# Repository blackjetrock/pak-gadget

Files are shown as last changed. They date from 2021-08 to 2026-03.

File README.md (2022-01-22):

# pak-gadget
Psion Organiser II datapak replacement using RP2040

Code for a replacement Psion datapak that uses the RP2040 to create a datapak image that is interfaced using one of the datapak slots in the Organiser.
The gadget has an SD slot that can hold .opk files which are presented to the organiser as a datapak. There's a small OLED display and buttons so the image can be selected. The pak gadget can also present a rampak and data can be stored on the ram pak. That can then be saved to SD card using the menu system.
Power is USB as the datapak interface does not have a permanent power supply.

There are two versions:

Breakout pak-gadget
===================

A 'breakout' pak-gadget which is a T shaped PCB that plugs in to the datapak slot and has the display and buttons facing forwards. This is quite large.

Pak Sized pak-gadget
====================

This is a pak-gadget that fits in the form factor of a datapak in the slot in the organiser. It has a smaller OLED display and buttons that both face towards the back of the organiser. Power is still USB. When disconnected from power the organiser cover should fit in the closed position. The gadget can be wired in to the internal power supply of the organiser.On older PCB designs this requires an external transistor and a wire to the gadget. The later designs have that on the gadget PCB and require two wires.

Operation
=========

The pak gadget plugs in to either datapack slot on a Psion Organiser 2. It can be powered by the USB socket on the PCB, or it can be wired in to the 
internal supply of the organiser. A transistor is needed to switch the battery voltage on to the gadget when the LCD controller is turned on. When wired in 
the USB connection MUST NOT be used. A later revision of the PCB (untested as yet) has the extra transistor needed for internal power on the PCB.

The gadget runs in a tight loop when emulating a datapack in order to operate at the speeds needed to interact with the Psion, which means it cannot handle a 
menu while emulating.

There are four buttons on the gadget. The left most button breaks the gadget out of its tight loop and starts a menu. UP and DOWN are the rightmost two 
buttons. The button second from left is an OK button.

The code reads a file called config.txt from the SD card when it starts up. At the moment this just sets the .OPK image that will initially be used.
pack header bytes are passed through from the OPk file to the organiser unchanged, apart from the size byte. The pak gadget can only support pack images up to 
and including 128K so the size byte is altered to be no larger than 128K.

Menu options
============

List
----
This lists the .OPK files on the SD card. Selecting a file loads it into the gadget RAM buffer ready to emulate it when the menu is exited.

Write
-----
This writes the current RAM data to a file on the SD card. This enables a pak gadget that has been used as a RAM pack to save the data on SD card so that 
it can be loaded back in later. When power is removed the RAM b uffer is lost so this is the only way to have non volatile storage with the pak gadget.

The files are written with the name:
paknnnnn.opk

where nnnnn is an increasing number for each file saved. The pak gadget checks for the last nnnnn used by a file on the SD card and picks the next 
highest number for each file write.

Blank
-----
This clears the RAM buffer and sets the pak gadget up as a blank pack which can then be sized and used as a RAM pack.

Exit
----
This exits the menu and enters the emulation loop so that the pak gadget will look like a datapack again. While in the menu system the gadget does not emulate a pack.

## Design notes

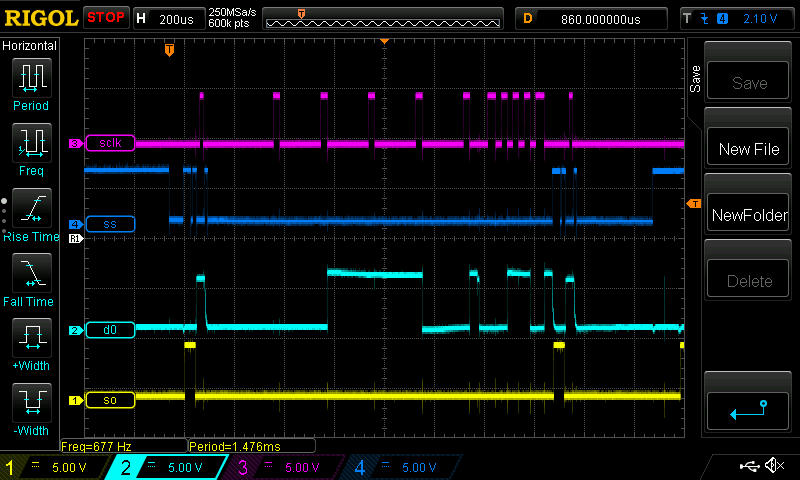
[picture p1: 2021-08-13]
eclipse/pak-gadget/scope_traces/rra2.jpg

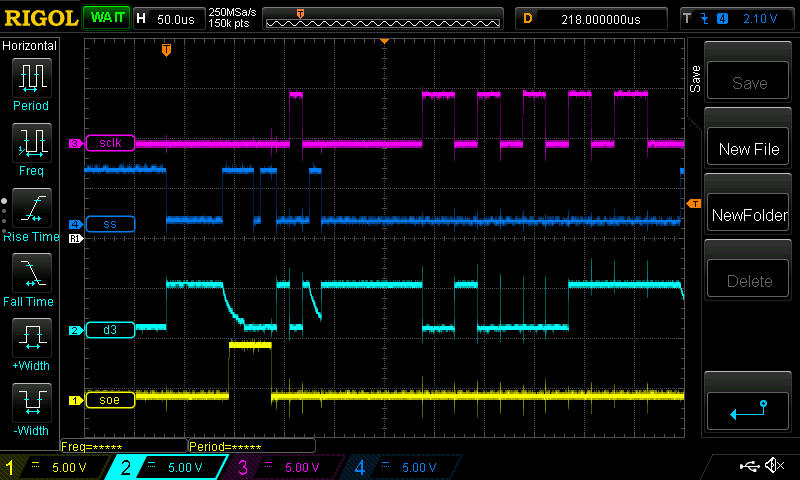
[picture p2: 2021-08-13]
eclipse/pak-gadget/scope_traces/NewFile3.jpg

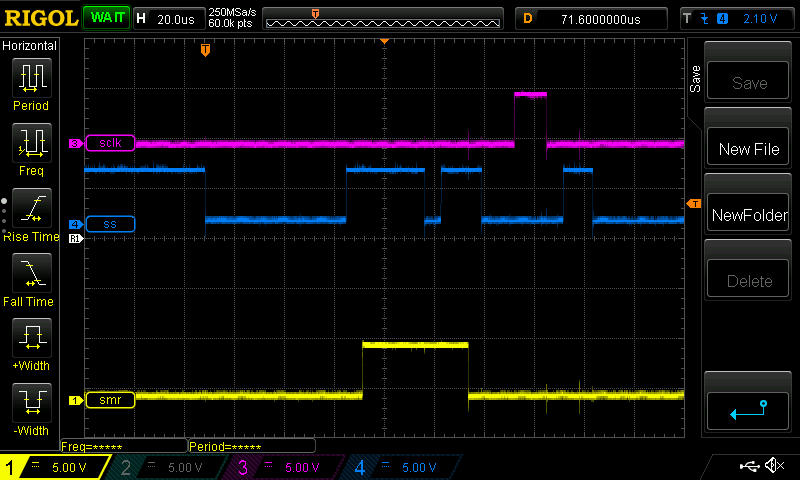
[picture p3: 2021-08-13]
eclipse/pak-gadget/scope_traces/rl_ra_smr.jpg

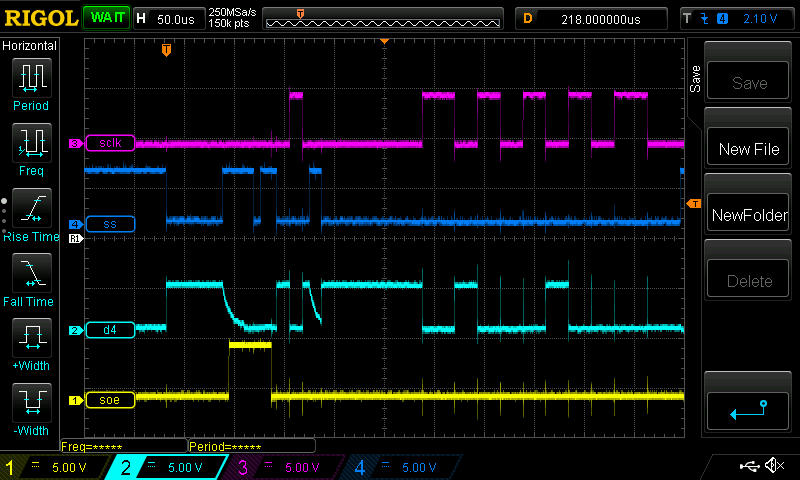
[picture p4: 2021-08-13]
eclipse/pak-gadget/scope_traces/NewFile5.jpg

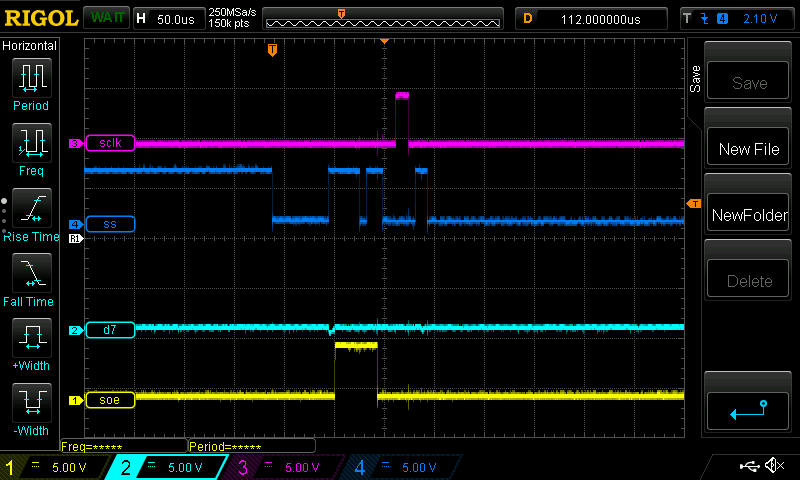
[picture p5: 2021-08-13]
eclipse/pak-gadget/scope_traces/NewFile8.jpg

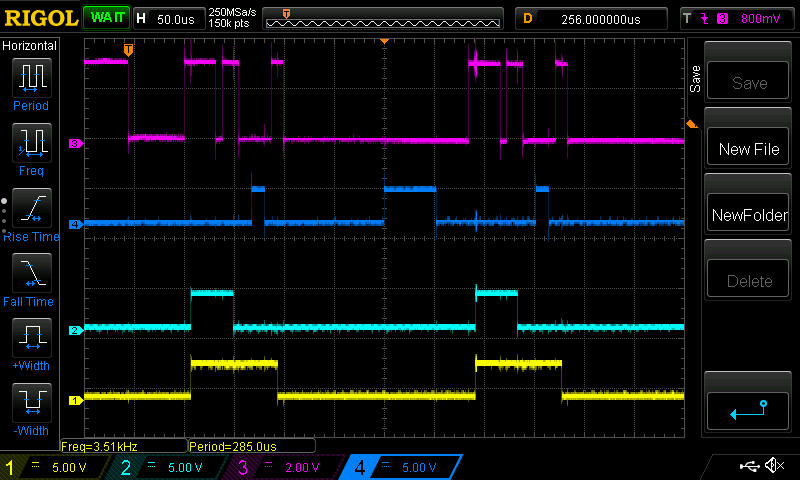
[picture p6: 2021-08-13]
eclipse/pak-gadget/scope_traces/smr1.jpg

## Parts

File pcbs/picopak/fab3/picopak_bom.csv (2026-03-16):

Comment | Designator | Footprint
Si2301 P chan | M1 | SOT-23
100k | R11 | C_0402_1005Metric
10k | R10 | C_0402_1005Metric
1M | R9,R8 | C_0402_1005Metric
Si2302CDS-n-channel | TR1 | SOT-23
Conn_01x02_Female | J5 | PinHeader_1x02_P1.00mm_Vertical_SMD_Pin1Left
PMEG3010ER | D1 | D_SOD-123
1k | R7,R5 | C_0402_1005Metric
Jumper_NO_Small | JP1 | SolderJumper-2_P1.3mm_Open_Pad1.0x1.5mm
Conn_01x03_Female | J3 | PinHeader_1x03_P1.00mm_Vertical_SMD_Pin1Left
10u | C4 | C_0402_1005Metric
27p | C2,C3 | C_0402_1005Metric
100n | C5,C6,C7,C14,C15,C16 | C_0402_1005Metric
1u | C8,C10 | C_0402_1005Metric
4k7 | R6,R1 | C_0402_1005Metric
47k | R15 | C_0402_1005Metric
74LS245 | U9,U10 | TSSOP-20_4.4x6.5mm_P0.65mm
RP2040 | U3 | RP2040-QFN-56-no_holes
ABLS-12.000MHZ-B4-T | Y1 | Crystal_SMD_3225-4Pin_3.2x2.5mm_HandSoldering
Conn_01x04_Female | J4 | OLED_SMALL
sw | SW4,SW3,SW2,SW1 | SW_Push_1P1T_NO_Vertical_Wuerth_434133025816
SD_ebay-uSD-push_push_SMD | XS1 | Conn_uSDcard
Conn_02x08_Odd_Even | J2 | Psion_datapak_2x08_P2.54mm_Horizontal
USB_B_Micro | J1 | USB_Micro-B_Amphenol_10103594-0001LF_Horizontal_modified
W25Q128JVS | U2 | SOIC-8_5.23x5.23mm_P1.27mm
NCP1117-3.3_SOT223 | U1 | SOT-223-3_TabPin2
27 | R4,R3 | C_0402_1005Metric
DNF | R2 | C_0402_1005Metric
10u | C1 | C_0805_2012Metric

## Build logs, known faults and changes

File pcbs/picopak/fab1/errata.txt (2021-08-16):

Picopak V1.0 errata

1. Display connector needs to be rotated 180 degrees, also move in slightly [DONE]
2. Resistor and capacitor footprints are too small, 0603 only just fits  [Using smaller components.]
3. Notch missing [
4. Switch footprint slightly wrong, too large. [leaving as OK to build]
5. Attempt to power from slot connector, maybe 5V can be persuaded to be on permanently? Or switched differently? 
6. Pull up resistors both go to SDA [FIXED]

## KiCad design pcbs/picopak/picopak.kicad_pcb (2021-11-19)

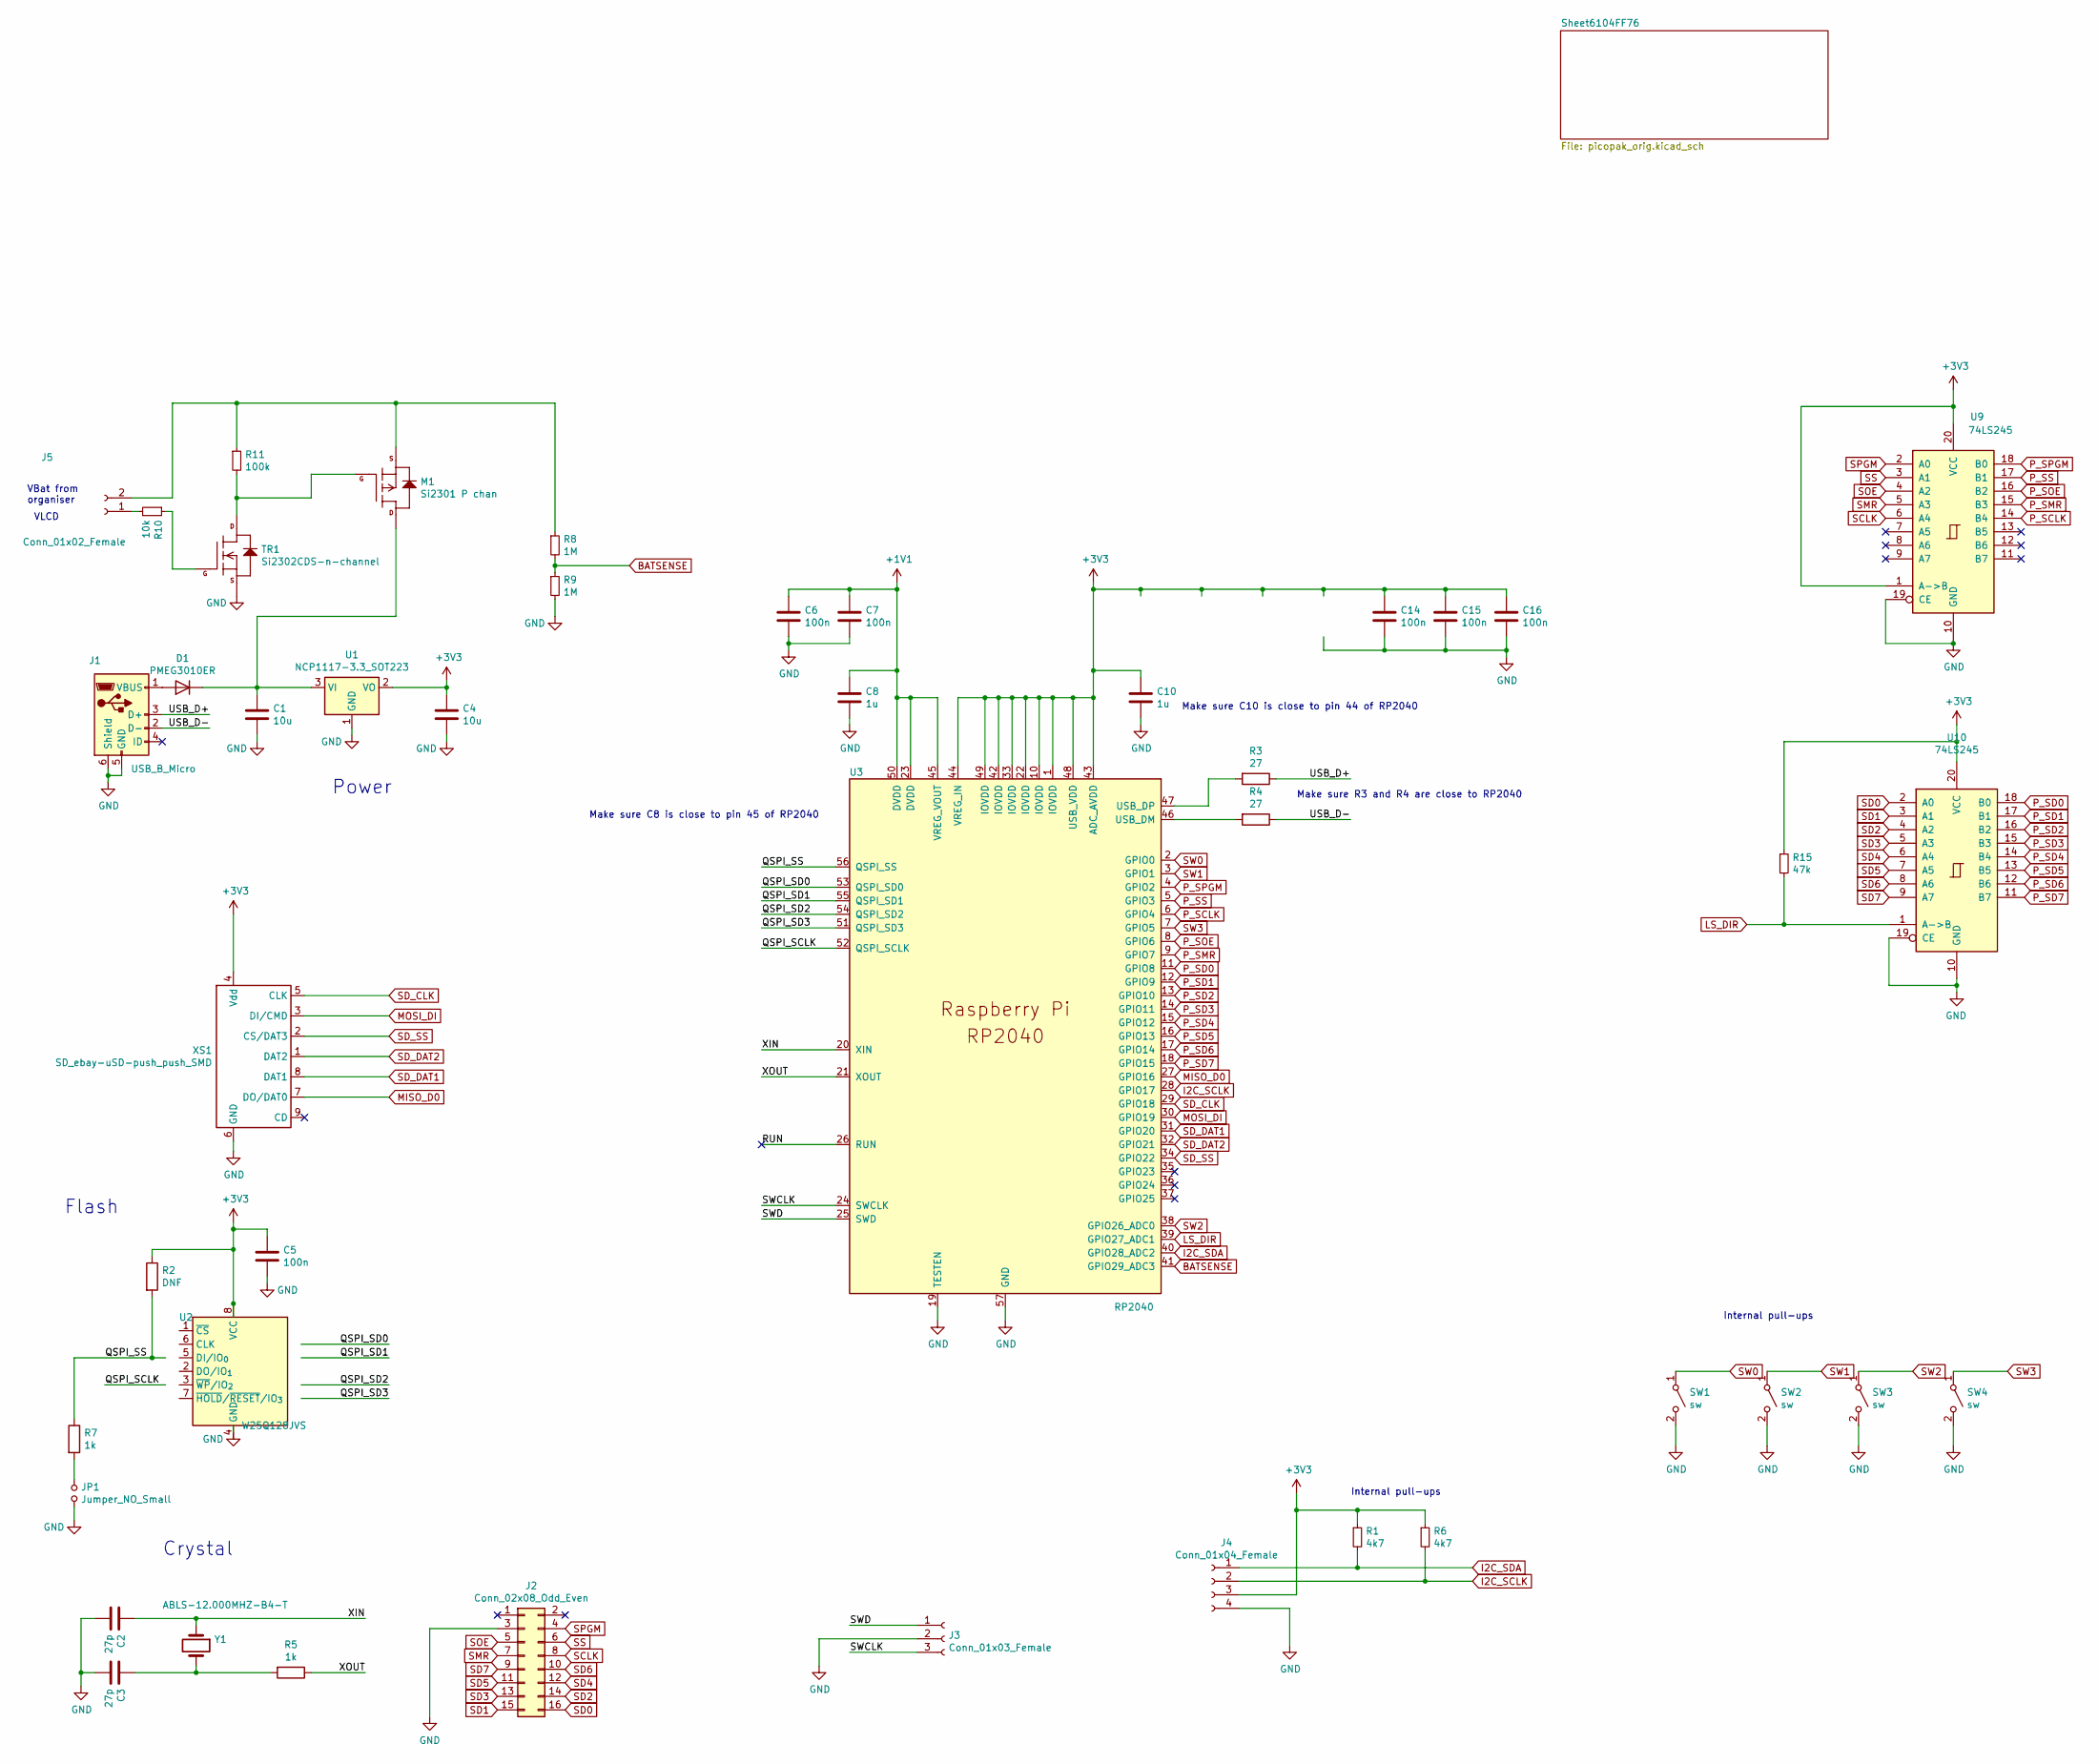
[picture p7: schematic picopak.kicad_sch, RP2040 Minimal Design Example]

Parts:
C1: 10u; C_0805_2012Metric
C2, C3: 27p; C_0402_1005Metric
C4: 10u; C_0402_1005Metric
C5, C6, C7, C14, C15, C16: 100n; C_0402_1005Metric
C8, C10: 1u; C_0402_1005Metric
D1: PMEG3010ER; D_SOD-123
J1: USB_B_Micro; USB_Micro-B_Amphenol_10103594-0001LF_Horizontal_modified
J2: Conn_02x08_Odd_Even; Psion_datapak_2x08_P2.54mm_Horizontal
J3: Conn_01x03_Female; PinHeader_1x03_P1.00mm_Vertical_SMD_Pin1Left
J4: Conn_01x04_Female; OLED_SMALL
J5: Conn_01x02_Female; PinHeader_1x02_P1.00mm_Vertical_SMD_Pin1Left
JP1: Jumper_NO_Small; SolderJumper-2_P1.3mm_Open_Pad1.0x1.5mm
M1: Si2301 P chan; SOT-23
R1, R6: 4k7; C_0402_1005Metric
R2: DNF; C_0402_1005Metric
R3, R4: 27; C_0402_1005Metric
R5, R7: 1k; C_0402_1005Metric
R8, R9: 1M; C_0402_1005Metric
R10: 10k; C_0402_1005Metric
R11: 100k; C_0402_1005Metric
R15: 47k; C_0402_1005Metric
SW1, SW2, SW3, SW4: sw; SW_Push_1P1T_NO_Vertical_Wuerth_434133025816
TR1: Si2302CDS-n-channel; SOT-23
U1: NCP1117-3.3_SOT223; SOT-223-3_TabPin2
U2: W25Q128JVS; SOIC-8_5.23x5.23mm_P1.27mm
U3: RP2040; RP2040-QFN-56-no_holes
U9, U10: 74LS245; TSSOP-20_4.4x6.5mm_P0.65mm
XS1: SD_ebay-uSD-push_push_SMD; Conn_uSDcard
Y1: ABLS-12.000MHZ-B4-T; Crystal_SMD_3225-4Pin_3.2x2.5mm_HandSoldering

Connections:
+1V1: C6.1, C7.1, C8.1, U3.23 (DVDD), U3.45 (VREG_VOUT), U3.50 (DVDD)
+3V3: C4.1, C5.1, C10.1, C14.1, C15.1, C16.1, J4.3, R1.1, R2.1, R6.1, R15.1, U1.2 (VO), U2.8 (VCC), U3.1 (IOVDD), U3.10 (IOVDD), U3.22 (IOVDD), U3.33 (IOVDD), U3.42 (IOVDD), U3.43 (ADC_AVDD), U3.44 (VREG_IN), U3.48 (USB_VDD), U3.49 (IOVDD), U9.1 (A->B), U9.20 (VCC), U10.20 (VCC), XS1.4 (Vdd)
/QSPI_SCLK: U2.6 (CLK), U3.52 (QSPI_SCLK)
/QSPI_SD0: U2.5 (DI/IO_{0}), U3.53 (QSPI_SD0)
/QSPI_SD1: U2.2 (DO/IO_{1}), U3.55 (QSPI_SD1)
/QSPI_SD2: U2.3 (~WP/IO_{2}), U3.54 (QSPI_SD2)
/QSPI_SD3: U2.7 (~HOLD/~RESET/IO_{3}), U3.51 (QSPI_SD3)
/QSPI_SS: R2.2, R7.1, U2.1 (~CS), U3.56 (QSPI_SS)
/SWCLK: J3.3, U3.24 (SWCLK)
/SWD: J3.1, U3.25 (SWD)
/USB_D+: J1.3 (D+), R3.1
/USB_D-: J1.2 (D-), R4.1
/XIN: C2.1, U3.20 (XIN), Y1.1
/XOUT: R5.1, U3.21 (XOUT)
BATSENSE: R8.2, R9.1, U3.41 (GPIO29_ADC3)
GND: C1.2, C2.2, C3.2, C4.2, C5.2, C6.2, C7.2, C8.2, C10.2, C14.2, C15.2, C16.2, J1.5 (GND), J1.6 (Shield), J2.3, J3.2, J4.4, JP1.2, R9.2, SW1.2 (B), SW2.2 (B), SW3.2 (B), SW4.2 (B), TR1.2 (S), U1.1 (GND), U2.4 (GND), U3.19 (TESTEN), U3.57 (GND), U9.10 (GND), U9.19 (CE), U10.10 (GND), U10.19 (CE), XS1.6 (GND)
I2C_SCLK: J4.2, R6.2, U3.28 (GPIO17)
I2C_SDA: J4.1, R1.2, U3.40 (GPIO28_ADC2)
LS_DIR: R15.2, U3.39 (GPIO27_ADC1), U10.1 (A->B)
MISO_D0: U3.27 (GPIO16), XS1.7 (DO/DAT0)
MOSI_DI: U3.30 (GPIO19), XS1.3 (DI/CMD)
unnamed: C1.1, D1.1 (K), M1.3 (D), U1.3 (VI)
unnamed: C3.1, R5.2, Y1.2
unnamed: D1.2 (A), J1.1 (VBUS)
unnamed: J5.1, R10.2
unnamed: J5.2, M1.2 (S), R8.1, R11.1
unnamed: JP1.1, R7.2
unnamed: M1.1 (G), R11.2, TR1.3 (D)
unnamed: R3.2, U3.47 (USB_DP)
unnamed: R4.2, U3.46 (USB_DM)
unnamed: R10.1, TR1.1 (G)
P_SCLK: U3.6 (GPIO4), U9.14 (B4)
P_SD0: U3.11 (GPIO8), U10.18 (B0)
P_SD1: U3.12 (GPIO9), U10.17 (B1)
P_SD2: U3.13 (GPIO10), U10.16 (B2)
P_SD3: U3.14 (GPIO11), U10.15 (B3)
P_SD4: U3.15 (GPIO12), U10.14 (B4)
P_SD5: U3.16 (GPIO13), U10.13 (B5)
P_SD6: U3.17 (GPIO14), U10.12 (B6)
P_SD7: U3.18 (GPIO15), U10.11 (B7)
P_SMR: U3.9 (GPIO7), U9.15 (B3)
P_SOE: U3.8 (GPIO6), U9.16 (B2)
P_SPGM: U3.4 (GPIO2), U9.18 (B0)
P_SS: U3.5 (GPIO3), U9.17 (B1)
SCLK: J2.8, U9.6 (A4)
SD0: J2.16, U10.2 (A0)
SD1: J2.15, U10.3 (A1)
SD2: J2.14, U10.4 (A2)
SD3: J2.13, U10.5 (A3)
SD4: J2.12, U10.6 (A4)
SD5: J2.11, U10.7 (A5)
SD6: J2.10, U10.8 (A6)
SD7: J2.9, U10.9 (A7)
SD_CLK: U3.29 (GPIO18), XS1.5 (CLK)
SD_DAT1: U3.31 (GPIO20), XS1.8 (DAT1)
SD_DAT2: U3.32 (GPIO21), XS1.1 (DAT2)
SD_SS: U3.34 (GPIO22), XS1.2 (CS/DAT3)
SMR: J2.7, U9.5 (A3)
SOE: J2.5, U9.4 (A2)
SPGM: J2.4, U9.2 (A0)
SS: J2.6, U9.3 (A1)
SW0: SW1.1 (A), U3.2 (GPIO0)
SW1: SW2.1 (A), U3.3 (GPIO1)
SW2: SW3.1 (A), U3.38 (GPIO26_ADC0)
SW3: SW4.1 (A), U3.7 (GPIO5)

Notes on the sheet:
Make sure R3 and R4 are close to RP2040
VLCD
Internal pull-ups
Make sure C10 is close to pin 44 of RP2040
Power
VBat from organiser
Crystal
Make sure C8 is close to pin 45 of RP2040
Flash

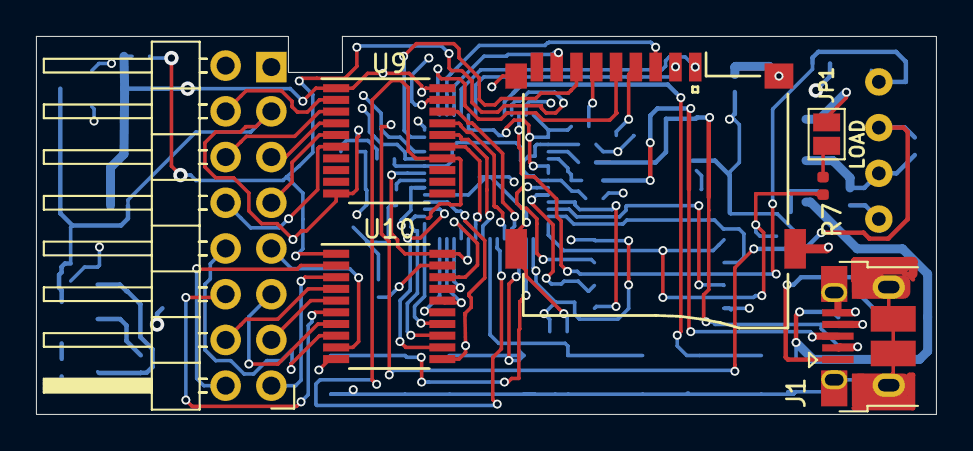
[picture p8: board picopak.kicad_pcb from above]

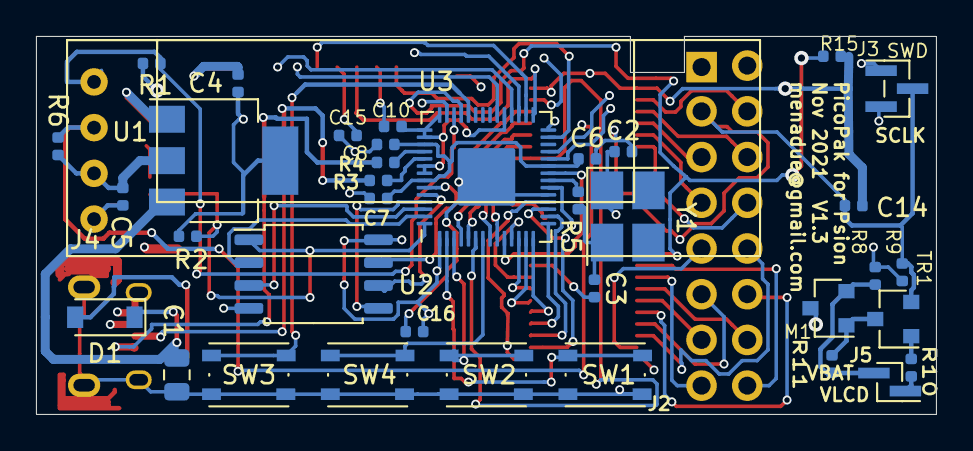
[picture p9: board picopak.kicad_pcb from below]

Board: 4 copper layers, 50.0 x 21.0 mm, 44 parts (37 on the bottom side), 65 nets.

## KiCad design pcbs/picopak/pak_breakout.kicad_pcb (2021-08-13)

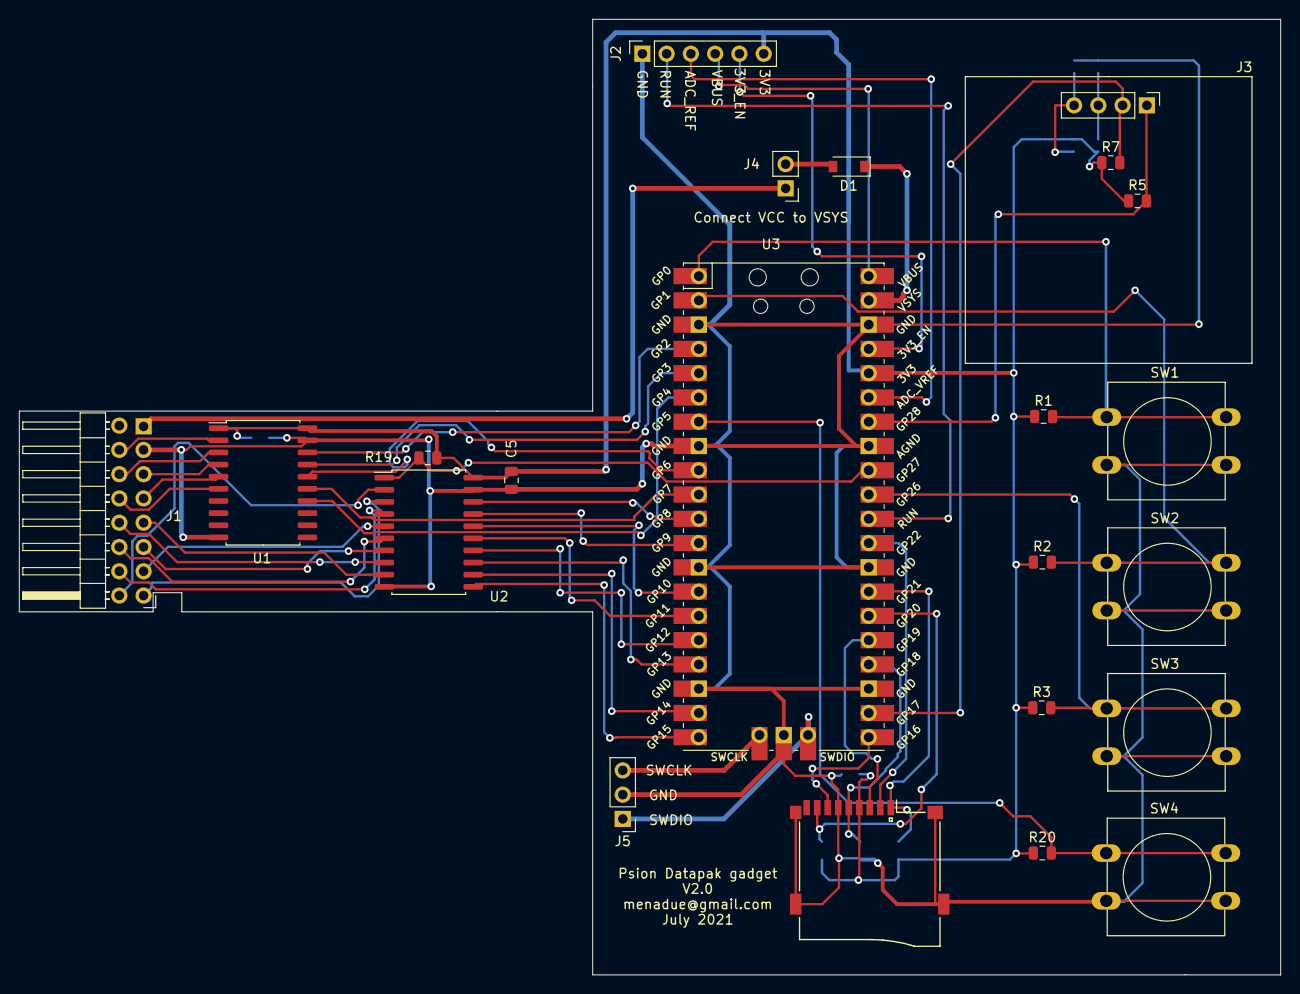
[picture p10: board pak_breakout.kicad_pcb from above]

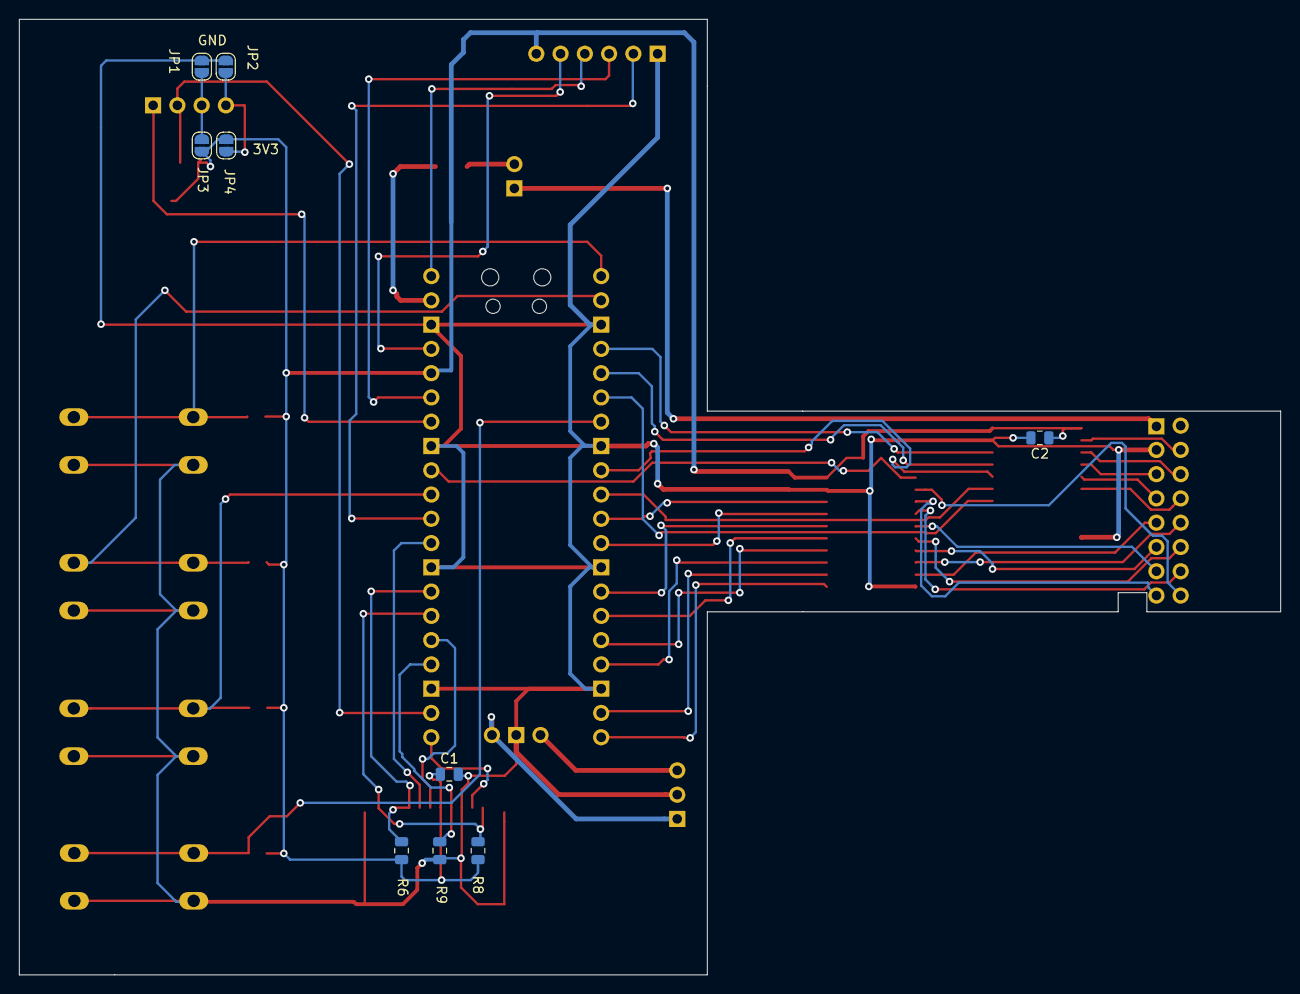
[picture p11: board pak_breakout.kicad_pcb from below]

Board: 2 copper layers, 132.0 x 100.0 mm, 31 parts (9 on the bottom side), 52 nets.

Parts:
C1: 1uF; C_0805_2012Metric
C2, C5: 100nF; C_0805_2012Metric
D1: D_Schottky; D_SOD-123
J1: Conn_02x08_Odd_Even; Psion_datapak_2x08_P2.54mm_Horizontal
J2: Conn_01x06_Female; PinSocket_1x06_P2.54mm_Vertical
J3: Conn_01x04_Female; PinHeader_1x04_P2.54mm_Vertical
J4: Conn_01x02_Female; PinHeader_1x02_P2.54mm_Vertical
J5: Conn_01x03_Female; PinHeader_1x03_P2.54mm_Vertical
JP1, JP2, JP3, JP4: Jumper_NO_Small; SolderJumper-2_P1.3mm_Open_RoundedPad1.0x1.5mm
R1, R2, R3, R20: 47k; R_0805_2012Metric
R5, R7: 4k7; R_0805_2012Metric
R6, R8, R9, R19: R_Small; R_0805_2012Metric
SW1, SW2, SW3, SW4: sw; SW_PUSH-12mm
U1, U2: 74LS245; SOIC-20W_7.5x12.8mm_P1.27mm
U3: Pico; RPi_Pico_SMD_TH
XS1: SD_ebay-uSD-push_push_SMD; Conn_uSDcard

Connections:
3V3_EN: J2.5, U3.37
+3V3: C1.1, C2.1, C5.1, J2.6, JP3.2, JP4.2, R1.1, R2.1, R3.1, R5.1, R6.1, R7.1, R8.1, R19.1, R20.1, U1.1, U1.20, U2.20, U3.36, XS1.4
ADC_REF: J2.3, U3.35
GND: C1.2, C2.2, C5.2, J1.3, J2.1, J5.2, JP1.2, JP2.2, R9.2, SW1.2, SW2.2, SW3.2, SW4.2, U1.10, U1.19, U2.10, U2.19, U3.3, U3.8, U3.13, U3.18, U3.23, U3.28, U3.33, U3.38, U3.42, XS1.6
I2C_SCLK: J3.2, R7.2, U3.22
I2C_SDA: J3.1, R5.2, U3.34
LS_DIR: R19.2, U2.1, U3.32
MISO_D0: U3.21, XS1.7
MOSI_DI: U3.25, XS1.3
unnamed: D1.1, U3.39
unnamed: D1.2, J4.2
unnamed: J3.3, JP1.1, JP3.1
unnamed: J3.4, JP2.1, JP4.1
unnamed: J5.1, U3.43
unnamed: J5.3, U3.41
P_SCLK: U1.14, U3.6
P_SD0: U2.18, U3.11
P_SD1: U2.17, U3.12
P_SD2: U2.16, U3.14
P_SD3: U2.15, U3.15
P_SD4: U2.14, U3.16
P_SD5: U2.13, U3.17
P_SD6: U2.12, U3.19
P_SD7: U2.11, U3.20
P_SMR: U1.15, U3.10
P_SOE: U1.16, U3.9
P_SPGM: U1.18, U3.4
P_SS: U1.17, U3.5
RUN: J2.2, U3.30
SCLK: J1.8, U1.6
SD0: J1.16, U2.2
SD1: J1.15, U2.3
SD2: J1.14, U2.4
SD3: J1.13, U2.5
SD4: J1.12, U2.6
SD5: J1.11, U2.7
SD6: J1.10, U2.8
SD7: J1.9, U2.9
SD_CLK: R9.1, U3.24, XS1.5
SD_DAT1: R8.2, U3.26, XS1.8
SD_DAT2: R6.2, U3.27, XS1.1
SD_SS: U3.29, XS1.2
SMR: J1.7, U1.5
SOE: J1.5, U1.4
SPGM: J1.4, U1.2
SS: J1.6, U1.3
SW0: R1.2, SW1.1, U3.1
SW1: R2.2, SW2.1, U3.2
SW2: R3.2, SW3.1, U3.31
SW3: R20.2, SW4.1, U3.7
VBUS: J2.4, U3.40
VCC: J1.1, J4.1

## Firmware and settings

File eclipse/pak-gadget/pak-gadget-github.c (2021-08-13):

#include <stdio.h>
#include "pico/stdlib.h"
//#include "hardware/i2c.h"
#include "hardware/pio.h"
#include "hardware/clocks.h"
#include "pico/multicore.h"

#include "f_util.h"
#include "ff.h"
#include "hw_config.h"
#include "my_debug.h"
#include "rtc.h"

// redefine pins to match our hardware
#define PICO_SD_CLK_PIN  5
#define PICO_SD_CMD_PIN  18
#define PICO_SD_DAT0_PIN 19
#define ENABLE_4_PIN 0
#include "sd_card.h"

#define SUPPORT_ID_BYTE  1
#define PAK_ID_BYTE      0x01
#define READ_ONLY        0
#define INIT_PAK_MEMORY  1
#define FF_FIRST_BYTES   0

#define DIRECT_GPIO  1

// Do we use a polling loop of interrupts?
#define USE_INTERRUPTS  0
#define USE_POLLING     1

#define MULTICORE_POLL   1

// The address into pak memory
#define PAK_ADDRESS (ss_address | ss_page)

const uint SDA_PIN    = 28;
const uint SCL_PIN    = 17;

#ifndef I2C_FUNCTIONS_H_
#define I2C_FUNCTIONS_H_

typedef unsigned char BYTE;

const int SLOT_SPGM_PIN = 2;
const int SLOT_SS_PIN   = 3;
const int SLOT_SCLK_PIN = 4;
const int SW3_PIN       = 5;
const int SLOT_SOE_PIN  = 6;
const int SLOT_SMR_PIN  = 7;

const int SLOT_SD0_PIN  = 8;
const int SLOT_SD1_PIN  = 9;
const int SLOT_SD2_PIN  = 10;
const int SLOT_SD3_PIN  = 11;
const int SLOT_SD4_PIN  = 12;
const int SLOT_SD5_PIN  = 13;
const int SLOT_SD6_PIN  = 14;
const int SLOT_SD7_PIN  = 15;

const int LS_DIR_PIN    = 27;

volatile int ss_count = 0;
volatile int soe_state = 1;
volatile int ss_address = 0;
volatile int ss_page = 0;


// Memory that emulates a pak
typedef unsigned char BYTE;

#define TRACE_LENGTH 8192
BYTE trace[TRACE_LENGTH];

int trace_i = 0;
//#define TRACE(XX) if(trace_i != (TRACE_LENGTH-1)) {trace[trace_i++] = XX; trace_i %= TRACE_LENGTH;}
#define TRACE(XX)

//#define WRITE_TRAP if( (PAK_ADDRESS + data) == 0)  while(1);

//#define WRITE_TRAP if( (ss_address + data + ss_page) == 0){  gpio_put(22,1);     gpio_put(22,0);}
#define WRITE_TRAP

#define PAK_MEMORY_SIZE  32768


#if !INIT_PAK_MEMORY
volatile BYTE pak_memory[PAK_MEMORY_SIZE];
#else

BYTE pak_memory[PAK_MEMORY_SIZE] =
  {
   
   0x78,0x04,0x56,0x00,0x03,0x02,0x35,0x46,0x06,0x4c,
   0x09,0x81,0x4d,0x41,0x49,0x4e,0x20,0x20,0x20,0x20,0x90,0x09,0x83,0x46,0x49,0x53,
   0x48,0x20,0x20,0x20,0x20,0x00,0x02,0x80,0x01,0x26,0x01,0x22,0x00,0x29,0x00,0xfc,
   0x00,0x00,0x13,0x02,0x59,0x25,0x00,0xff,0xe9,0x03,0x44,0x52,0x24,0x02,0xff,0xe6,
   0x02,0x46,0x24,0x02,0xff,0xdc,0x00,0x00,0x00,0x06,0xff,0xe5,0x02,0xff,0xdb,0x08,
   0x00,0x00,0x0f,0xff,0xdc,0x24,0x04,0x46,0x49,0x53,0x48,0x20,0x02,0x20,0x01,0x7d,
   0x06,0x45,0x58,0x49,0x53,0x54,0x24,0x81,0x02,0xff,0xdc,0x24,0x00,0x4a,0x7e,0x00,
   0x32,0x0d,0xff,0xd9,0x24,0x10,0x43,0x52,0x45,0x41,0x54,0x45,0x2d,0x46,0x49,0x4c,
   0x45,0x2c,0x51,0x55,0x49,0x54,0x98,0x7f,0x00,0xff,0xd9,0x022,0x00,0x01,0x2c,0x7e,
   0x00,0x10,0x20,0x00,0x7d,0x06,0x46,0x49,0x53,0x48,0x43,0x52,0x84,0x51,0x00,0x03,
   0x7b,0x20,0x00,0x7d,0x06,0x46,0x49,0x53,0x48,0x4f,0x50,0x84,0x20,0x00,0x7d,0x06,
   0x4d,0x41,0x44,0x55,0x44,0x47,0x84,0x0d,0xff,0xd7,0x24,0x20,0x41,0x44,0x44,0x2d,
   0x4e,0x45,0x57,0x2d,0x46,0x49,0x53,0x48,0x2c,0x53,0x45,0x41,0x52,0x43,0x48,0x2c,
   0x52,0x45,0x50,0x4f,0x52,0x54,0x2c,0x55,0x54,0x49,0x4c,0x53,0x98,0x7f,0x00,0xff,
   0xd7,0x22,0x00,0x01,0x2c,0x7e,0x00,0x14,0x20,0x00,0x7d,0x07,0x46,0x49,0x53,0x48,
   0x41,0x44,0x44,0x84,0x51,0xff,0xc2,0x51,0x00,0x55,0x00,0xff,0xd7,0x22,0x00,0x02,
   0x2c,0x7e,0x00,0x14,0x20,0x00,0x7d,0x07,0x46,0x49,0x53,0x48,0x53,0x45,0x45,0x84,
   0x51,0xff,0xa6,0x51,0x00,0x39,0x00,0xff,0xd7,0x22,0x00,0x03,0x2c,0x7e,0x00,0x14,
   0x20,0x00,0x7d,0x07,0x46,0x49,0x53,0x48,0x52,0x45,0x50,0x84,0x51,0xff,0x8a,0x51,
   0x00,0x1d,0x00,0xff,0xd7,0x22,0x00,0x04,0x2c,0x7e,0x00,0x12,0x20,0x00,0x7d,0x05,
   0x55,0x54,0x49,0x4c,0x53,0x84,0x51,0xff,0x70,0x51,0x00,0x03,0x7b,0x7b,0x00,0x00,
   0x09,0x83,0x46,0x49,0x53,0x48,0x41,0x44,0x44,0x20,0x00,0x02,0x80,0x06,0x11,0x06,
   0x0d,0x00,0x3a,0x05,0xee,0x00,0x00,0x00,0x00,0x00,0x00,0x12,0xff,0xf4,0x06,0xff,
   0xe6,0x04,0xff,0xe2,0x02,0xff,0xde,0x02,0xff,0xd8,0x04,0xff,0xc6,0x10,0x00,0x00,
   0x4e,0x24,0x0f,0x45,0x58,0x45,0x20,0x74,0x6f,0x20,0x63,0x6f,0x6e,0x74,0x69,0x6e,
   0x75,0x65,0x71,0x73,0x24,0x0d,0x43,0x4c,0x45,0x41,0x52,0x20,0x74,0x6f,0x20,0x71,
   0x75,0x69,0x74,0x71,0x73,0x0d,0xff,0xfc,0x91,0x7f,0x00,0xff,0xfc,0x22,0x00,0x0d,
   0x2b,0x7e,0x00,0x03,0x7b,0x4e,0x62,0x24,0x04,0x44,0x41,0x59,0x24,0x1f,0x00,0xb9,
   0x22,0x00,0x10,0xc0,0x81,0x0f,0xff,0xc7,0x24,0x04,0x44,0x41,0x59,0x24,0x1c,0x00,
   0x81,0x24,0x04,0x44,0x41,0x59,0x24,0x1f,0x00,0x6b,0x24,0x04,0x44,0x41,0x59,0x24,
   0x1c,0x00,0x02,0xff,0xc7,0x49,0x7e,0x00,0x85,0x53,0xff,0xff,0x24,0x04,0x44,0x41,
   0x59,0x24,0x1f,0x00,0x24,0x04,0x44,0x41,0x59,0x24,0x1c,0x00,0x22,0x00,0x10,0xc0,
   0x81,0x22,0x00,0x03,0x6a,0x0f,0xff,0xe3,0x8c,0x86,0x22,0x00,0x02,0xbc,0x81,0x0f,
   0xff,0xdf,0x9a,0x86,0x22,0x00,0x02,0xbc,0x81,0x0f,0xff,0xd9,0xa1,0x86,0x22,0x00,
   0x04,0xbc,0x81,0x22,0x00,0x01,0x22,0x00,0x02,0x4c,0x0f,0xff,0xe3,0x6b,0x22,0x00,
   0x04,0x22,0x00,0x02,0x4c,0x0f,0xff,0xdf,0x6b,0x22,0x00,0x08,0x22,0x00,0x02,0x4c,
   0x0f,0xff,0xd9,0x6b,0x24,0x01,0x44,0x1e,0x00,0x02,0xff,0xe3,0xb5,0x02,0xff,0xdf,
   0xb5,0x22,0x00,0x64,0x86,0x3e,0x3c,0x02,0xff,0xd9,0xb5,0x22,0x27,0x10,0x86,0x3e,
   0x3c,0x80,0x22,0x00,0x01,0x6a,0x53,0x00,0x00,0x51,0x00,0x24,0x24,0x01,0x44,0x1e,
   0x00,0xa1,0x86,0x80,0x24,0x01,0x44,0x1e,0x00,0x24,0x01,0x44,0x1b,0x00,0x22,0x27,
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
  };
#endif

////////////////////////////////////////////////////////////////////////////////
//
typedef struct {
  FATFS fatfs;
  char const *const name;
} fatfs_dscr_t;

static fatfs_dscr_t fatfs_dscrs[2] = {{.name = "0:"}, {.name = "1:"}};
static FATFS *get_fs_by_name(const char *name) {
  for (size_t i = 0; i < count_of(fatfs_dscrs); ++i) {
    if (0 == strcmp(fatfs_dscrs[i].name, name)) {
      return &fatfs_dscrs[i].fatfs;
    }
  }
  return NULL;

}

static bool logger_enabled;
static const uint32_t period = 1000;
static absolute_time_t next_time;

////////////////////////////////////////////////////////////////////////////////



// I2C Port descriptor
typedef struct _I2C_PORT_DESC
{
  unsigned char sdaport;
  unsigned char sdabit;
  unsigned char sclport;
  unsigned char sclbit;
} I2C_PORT_DESC;

// Slave device descriptor
typedef struct _I2C_SLAVE_DESC
{
  I2C_PORT_DESC *port;             // Port the device is on
  unsigned char slave_7bit_addr;        // SLave address
} I2C_SLAVE_DESC;

// I2C functions
void i2c_release(I2C_PORT_DESC *port);
void i2c_delay(I2C_PORT_DESC *port);
void i2c_sda_low(I2C_PORT_DESC *port);
void i2c_sda_high(I2C_PORT_DESC *port);
void i2c_scl_low(I2C_PORT_DESC *port);
void i2c_scl_high(I2C_PORT_DESC *port);
void i2c_start(I2C_PORT_DESC *port);
void i2c_stop(I2C_PORT_DESC *port);
int i2c_send_byte(I2C_PORT_DESC *port, BYTE b);
int i2c_read_bytes(I2C_SLAVE_DESC *slave, int n, BYTE *data);
void i2c_send_bytes(I2C_SLAVE_DESC *slave, int n, BYTE *data);
#

#endif /* I2C_FUNCTIONS_H_ */


/*
 * i2c_functions.c
 *
 *  Created on: 23 Jul 2016
 *      Author: menadue
 */
//#include "chip.h"
//#include "board.h"
//#include "i2c_functions.h"


// I2C functions

// Release the bus
void i2c_release(I2C_PORT_DESC *port) {
  // All inputs
  gpio_set_dir(SDA_PIN,GPIO_IN);
  gpio_set_dir(SCL_PIN,GPIO_IN);
  //  Chip_GPIO_SetPinDIRInput(LPC_GPIO, port->sdaport, port->sdabit);
  //Chip_GPIO_SetPinDIRInput(LPC_GPIO, port->sclport, port->sclbit);
}

// Delay to slow down to I2C bus rates
void i2c_delay(I2C_PORT_DESC *port) {
  sleep_us(10);
  return;
  volatile int i;
  for(i=0; i<1; i++)
    {
    }
  
}

void i2c_sda_low(I2C_PORT_DESC *port) {
  // Take SCL low by driving a 0 on to the bus
  gpio_put(SDA_PIN, 0);
  gpio_set_dir(SDA_PIN,GPIO_OUT);
  //Chip_GPIO_SetPinState(LPC_GPIO, port->sdaport, port->sdabit, 0);
  
  // Make sure bit is an output
  //Chip_GPIO_SetPinDIROutput(LPC_GPIO, port->sdaport, port->sdabit);
}

void i2c_sda_high(I2C_PORT_DESC *port) {
  // Make sure bit is an intput
  gpio_set_dir(SDA_PIN,GPIO_IN);

  //  Chip_GPIO_SetPinDIRInput(LPC_GPIO, port->sdaport, port->sdabit);
}

void i2c_scl_low(I2C_PORT_DESC *port) {

  gpio_put(SCL_PIN, 0);
  gpio_set_dir(SCL_PIN,GPIO_OUT);

  //  Chip_GPIO_SetPinState(LPC_GPIO, port->sclport, port->sclbit, 0);

  // Make sure bit is an output
  //Chip_GPIO_SetPinDIROutput(LPC_GPIO, port->sclport, port->sclbit);
}

void i2c_scl_high(I2C_PORT_DESC *port)
{
  // Make sure bit is an input
  gpio_set_dir(SCL_PIN,GPIO_IN);
  //Chip_GPIO_SetPinDIRInput(LPC_GPIO, port->sclport, port->sclbit);
}

// Read ACK bit

int i2c_read_sda(I2C_PORT_DESC *port)
{
  return(gpio_get(SDA_PIN));
  //  return(Chip_GPIO_GetPinState(LPC_GPIO, port->sdaport, port->sdabit));

  //  return( ((*(port->port)) & (port->sda_mask)) == port->sda_mask);
}

// I2C start condition

void i2c_start(I2C_PORT_DESC *port)
{
  //
  i2c_sda_low(port);

  i2c_delay(port);
  i2c_scl_low(port);
  i2c_delay(port);
}

void i2c_stop(I2C_PORT_DESC *port)
{
  i2c_scl_high(port);
  i2c_delay(port);
  i2c_sda_high(port);
  i2c_delay(port);

}

// Send 8 bits and read ACK
// Returns number of acks received

int i2c_send_byte(I2C_PORT_DESC *port, BYTE b)
{
  int i;
  int ack=0;
  int retries = 100;
  int rc =1;

  for (i = 0; i < 8; i++)
    {
      // Set up data
      if ((b & 0x80) == 0x80)
	{
	  i2c_sda_high(port);
	} else
	{
	  i2c_sda_low(port);
	}

      // Delay
      i2c_delay(port);

      // Take clock high and then low
      i2c_scl_high(port);

      // Delay
      i2c_delay(port);

      // clock low again
      i2c_scl_low(port);

      // Delay
      i2c_delay(port);

      // Shift next data bit in
      b <<= 1;
    }

  // release data line
  i2c_sda_high(port);

  // Now get ACK
  i2c_scl_high(port);

  i2c_delay(port);

  // read ACK

  while( ack = i2c_read_sda(port) ) // @suppress("Assignment in condition")
    {
      retries--;

      if ( retries == 0 )
	{
	  rc = 0;
	  break;
	}
    }

  i2c_scl_low(port);

  i2c_delay(port);
  return (rc);
}


// Receive 8 bits and set ACK
// Ack as specified
void i2c_recv_byte(I2C_PORT_DESC *port, BYTE *data, int ack)
{
  int i, b;

  b = 0;

  // Make data an input
  i2c_sda_high(port);

  for (i = 0; i < 8; i++)
    {
      // Delay
      i2c_delay(port);

      // Take clock high and then low
      i2c_scl_high(port);

      // Delay
      i2c_delay(port);

      // Shift next data bit in
      b <<= 1;
      b += (i2c_read_sda(port) & 0x1);

      // clock low again
      i2c_scl_low(port);

      // Delay
      i2c_delay(port);

    }

  // ACK is as we are told 
  if ( ack )
    {
      // Data low for ACK
      i2c_sda_low(port);
    }
  else
    {
      i2c_sda_high(port);
    }

  // Now send ACK
  i2c_scl_high(port);

  i2c_delay(port);

  i2c_scl_low(port);

  i2c_delay(port);

  *data = b;

}

// Reads a block of bytes from a slave

int i2c_read_bytes(I2C_SLAVE_DESC *slave, int n, BYTE *data)
{
  int i;
  BYTE byte;

  i2c_start(slave->port);

  // Send slave address with read bit
  if ( !i2c_send_byte(slave->port, ((slave->slave_7bit_addr) << 1) | 1) )
    {
      i2c_stop(slave->port);
      return(0);
    }


  //
  for (i = 0; i < n; i++)
    {
      i2c_recv_byte(slave->port, &byte, (i==(n-1))? 0 : 1);
      *(data++) = byte;
    }

  i2c_stop(slave->port);

  return(1);
}

// Sends a block of data to I2C slave
void i2c_send_bytes(I2C_SLAVE_DESC *slave, int n, BYTE *data)
{
  int i;

  i2c_start(slave->port);

  // Send slave address with read bit
  i2c_send_byte(slave->port, ((slave->slave_7bit_addr) << 1) | 0);

  //
  for (i = 0; i < n; i++)
    {
      i2c_send_byte(slave->port, *(data++));
    }

  i2c_stop(slave->port);
}

void i2c_init(I2C_PORT_DESC *port)
{
  gpio_init(SDA_PIN);
  gpio_init(SCL_PIN);
  //Chip_GPIO_SetPinDIROutput(LPC_GPIO, 0, 19);
  //Chip_GPIO_SetPinDIROutput(LPC_GPIO, 0, 2);
  //Chip_GPIO_SetPinDIROutput(LPC_GPIO, 0, 18);
  //Chip_GPIO_SetPinDIROutput(LPC_GPIO, 0, 7);
  //Chip_GPIO_SetPinDIROutput(LPC_GPIO, 1, 19);
  //Chip_GPIO_SetPinDIROutput(LPC_GPIO, 1, 20);
}

/*
 * oled096.h
 *
 *  Created on: 23 Jul 2016
 *      Author: menadue
 */

#ifndef OLED096_H_
#define OLED096_H_

#define I2C_CMD       1
#define I2C_DATA      0
#define I2C_REPEAT    1
#define I2C_NO_REPEAT 0

void oled_send_cmd(I2C_SLAVE_DESC *slave, int n, unsigned char *data, int command, int repeat);
void oled_set_xy(I2C_SLAVE_DESC *slave, int x, int y);
void oled_set_pixel_xy(I2C_SLAVE_DESC *slave, int x, int y);
void oled_set_byte_xy(I2C_SLAVE_DESC *slave, int x, int y, int b);
void oled_gap(I2C_SLAVE_DESC *slave);
void oled_display_int(I2C_SLAVE_DESC *slave, long int n, int num_digits);
void oled_display_string(I2C_SLAVE_DESC *slave, char *string);
void oled_clear_display(I2C_SLAVE_DESC *slave);

void oled_setup(I2C_SLAVE_DESC *slave);
void oled_display_scaled_string_xy(I2C_SLAVE_DESC *slave, char *string, int x, int y, int scale);

extern const unsigned char font_5x7_letters[];

#endif /* OLED096_H_ */

/*
 * oled096.c
 *
 *  Created on: 23 Jul 2016
 *      Author: menadue
 */

//
// 0.96" OLED display functions
//


// Sends a block of commands to the SSD1306
// command causes 80 to be sent before each byte
// command = 0 causes 0x40 and just data bytes
// Repeat = 1, repeat data byte 0

//#include <string.h>
//#include "i2c_functions.h"
//#include "oled096.h"

void oled_send_cmd(I2C_SLAVE_DESC *slave, int n, unsigned char *data, int command, int repeat)
{
  int i;

  i2c_start(slave->port);

  // Send slave address
  i2c_send_byte(slave->port, (slave->slave_7bit_addr)<<1);

  if ( !command )
    {
      i2c_send_byte(slave->port, 0x40);
    }

  // Send the command bytes, each preceded bu 0x80 (continuation)
  for (i = 0; i < n; i++) {
    if ( command )
      {
        i2c_send_byte(slave->port, 0x80);
      }
    i2c_send_byte(slave->port, *data);

    if ( !repeat )
      {
	data++;
      }
  }

  i2c_stop(slave->port);
}
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
int main()
{
#if FF_FIRST_BYTES
  for(int k=0; k< 100; k++)
    {
      pak_memory[k] = 0xff;
    }
#endif

  stdio_init_all();
  //time_init();
  //adc_init();

  gpio_init(22);
  
  // Select the SD card
  gpio_put(22, 0);
  gpio_set_dir(22, GPIO_OUT);
  gpio_put(22, 0);
  
  // Set up directions for the control lines
  gpio_init(SLOT_SS_PIN);
  gpio_init(SLOT_SCLK_PIN);
  gpio_init(SLOT_SMR_PIN);
  gpio_init(SLOT_SOE_PIN);
  gpio_init(SLOT_SPGM_PIN);

  for(int i=0; i<8; i++)
    {
      gpio_init(data_gpio[i]);
    }
  
  gpio_set_dir(SLOT_SS_PIN, GPIO_IN);
  gpio_set_dir(SLOT_SCLK_PIN, GPIO_IN);
  gpio_set_dir(SLOT_SMR_PIN, GPIO_IN);
  gpio_set_dir(SLOT_SOE_PIN, GPIO_IN);
  gpio_set_dir(SLOT_SPGM_PIN, GPIO_IN);

  // Drive data bus towards us
  gpio_init(LS_DIR_PIN);
  gpio_put(LS_DIR_PIN, 1);

  // LS_DIR is an output
  gpio_set_dir(LS_DIR_PIN, GPIO_OUT);
  set_bus_inputs();

#if USE_INTERRUPTS
  gpio_set_irq_enabled_with_callback(SLOT_SS_PIN,   GPIO_IRQ_EDGE_RISE | GPIO_IRQ_EDGE_FALL, true, &gpio_callback);
  gpio_set_irq_enabled_with_callback(SLOT_SCLK_PIN, GPIO_IRQ_EDGE_RISE | GPIO_IRQ_EDGE_FALL, true, &gpio_callback);
  gpio_set_irq_enabled_with_callback(SLOT_SMR_PIN,  GPIO_IRQ_EDGE_RISE | GPIO_IRQ_EDGE_FALL, true, &gpio_callback);
  gpio_set_irq_enabled_with_callback(SLOT_SOE_PIN,  GPIO_IRQ_EDGE_RISE | GPIO_IRQ_EDGE_FALL, true, &gpio_callback);
  gpio_set_irq_enabled_with_callback(SLOT_SPGM_PIN, GPIO_IRQ_EDGE_RISE | GPIO_IRQ_EDGE_FALL, true, &gpio_callback);
#endif
  
  sd_init_driver();
    
  printf("\033[2J\033[H");  // Clear Screen
  printf("\n> ");
  stdio_flush();

  // Set up OLED display
  i2c_init(&i2c_bus_0);
    
  oled_setup(&oled0);
    
  oled_set_xy(&oled0, 0,0);
  oled_display_string(&oled0, "Datapak Gadget");

#if USE_INTERRUPTS
  oled_set_xy(&oled0, 0,14);
  oled_display_string(&oled0, "Interrupts");
#endif

#if USE_POLLING
  oled_set_xy(&oled0, 0,14);
  oled_display_string(&oled0, "Polling");
#endif
  
  int count = 0;

#if MULTICORE_POLL
  // Start the address handling on the other core
  multicore_launch_core1(handle_address);
#endif
  
  // Main loop that updates OLED display if using interrupts
#if USE_INTERRUPTS
  for (;;)
    {
#if 1
      // Monitor the SS line and count how many falling edges there are
      
      char line[80];
      sprintf(line, "%d %d %d %d        ", count, ss_count, ss_address, soe_state);
      oled_set_xy(&oled0, 0, 21);
      oled_display_string(&oled0, line);
      
      count++;
#endif

    }
#endif  

#if USE_POLLING
  // Use a polling loop for minimum latency

  while(1)
    {
  int last_ss;
  int last_sclk;
  int last_soe;
  int last_smr;
  int last_spgm;
  
  last_ss     = gpio_get(SLOT_SS_PIN);
  last_sclk   = gpio_get(SLOT_SCLK_PIN);
  last_soe    = gpio_get(SLOT_SOE_PIN);
  last_smr    = gpio_get(SLOT_SMR_PIN);
  last_spgm   = gpio_get(SLOT_SPGM_PIN);

  int ss;
  int sclk;
  int soe;
  int smr;
  int spgm;


  // Turn off timer interrupts
  irq_set_mask_enabled(0xf, false);

  while(1)
    {
      
      // Read GPIO states
      ss     = gpio_get(SLOT_SS_PIN);
      sclk   = gpio_get(SLOT_SCLK_PIN);
      soe    = gpio_get(SLOT_SOE_PIN);
      smr    = gpio_get(SLOT_SMR_PIN);
      spgm   = gpio_get(SLOT_SPGM_PIN);
      
      // Waste some time signalling start of loop
      //gpio_put(22,1);

      
      if( (last_ss == 1) && (ss == 0) )
	{
	  // We are selected, look at SOE to see if we should drive the data bus or not
	  if ( soe )
	    {
	      int data;
	      
	      // High so don't drive the data bus, this is either a write or
	      // it is a write of the 128K EPROM segment register
	      
	      // Capture data on bus
	      set_bus_inputs();
	      data = get_data_bus();

	      if( smr == 1 )
		{
		  // Segment register write
		  TRACE('s');
		  TRACE(data);
		}
	      else
		{
		  TRACE('W');
		  TRACE(data);
		  TRACE(ss_address & 0xff);
		  TRACE(ss_address >> 8);
		  
#if !READ_ONLY	      
		  // write to ram
		  WRITE_TRAP;
		  pak_memory[PAK_ADDRESS] = data;
#endif
		}
	    }
	  else
	    {
	      // Low, so this is a read
	      // Is it a read of the pak ID?
	      //	      if( gpio_get(SLOT_SMR_PIN) && gpio_get(SLOT_SPGM_PIN) )
	      if( smr && spgm )
		{
		  // ID byte
		  set_bus_outputs();
#if SUPPORT_ID_BYTE
		  TRACE('I');
		  TRACE(PAK_ID_BYTE);
		  set_data_bus(PAK_ID_BYTE);
#else
		  TRACE('W');
		  TRACE(pak_memory[PAK_ADDRESS]);
		  TRACE(ss_address & 0xff);
		  TRACE(ss_address >> 8);

		  set_data_bus(pak_memory[PAK_ADDRESS]);
#endif
		}
	      else
		{
		  // Read of pak memory
		  set_bus_outputs();
		  TRACE('r');
		  TRACE(pak_memory[ss_address]);
		  set_data_bus(pak_memory[PAK_ADDRESS]);
		}
	    }
	}
      
      if( (last_ss == 0 ) && (ss == 1) )
	{
	  // SS high, so we are de-selected
	  //gpio_put(22,1);
	  //gpio_put(22,0);

	  set_bus_inputs();
	  
	  if ( soe )
	    {
	      int data;
	      
	      // High so don't drive the data bus, this is either a write of the
	      // 128K EPROM segment register or a write
	      
	      // Capture data on bus
	      //	      set_bus_inputs();
	      data = get_data_bus();

	      if( smr == 1 )
		{
		  // 128K segment write
		  TRACE('s');
		  TRACE(data);
		}
	      else
		{
		  TRACE('w');
		  TRACE(data);
		  TRACE(ss_address & 0xff);
		  TRACE(ss_address >> 8);


#if !READ_ONLY	      
		  // write to ram
		  WRITE_TRAP;
		  pak_memory[PAK_ADDRESS] = data;
#endif
		}
	    }
	}

#if !MULTICORE_POLLING      
      //----------------------------------------------------------------------
      // SCLK handling
      // The lower address bit is the CLK line
      // Falling edge
      if( (last_sclk == 1) && (sclk == 0))
	{
#if 0	  
	  ss_address+=2;
	  ss_address &= (~1);
	  
	  // Wrap address
	  ss_address &= PAK_MEMORY_SIZE - 1;
#endif
	}

      
      // Rising edge
      if( (last_sclk == 0) && (sclk == 1))
	{
	  //	  ss_address |= 1;
	  
	  // We now have to present data if we are selected
	  if( ss == 0 )
	    {
	      // We are selected, look at SOE to see if we should drive the data bus or not
	      if ( soe )
		{
		  int data;
		  
		  // High so don't drive the data bus, this is a write
		  // Capture data on bus
		  set_bus_inputs();

		  // We don't write here as SS hasn't gone high and OE hasn't gone high
		  //data = get_data_bus();

#if !READ_ONLY		  
		  // write to ram
		  //pak_memory[PAK_ADDRESS] = data;
#endif
		}
	      else
		{
		  // Low, so this is a read
		  // Is it a read of the pak ID?
		  if( smr && spgm )
		    {
		      TRACE('I');
		      TRACE('D');
		      // ID byte
		      set_bus_outputs();
		      set_data_bus(PAK_ID_BYTE);
		    }
		  else
		    {
		      // Read of pak memory
		      TRACE('R');
		      TRACE('D');
		      TRACE(pak_memory[PAK_ADDRESS]);
		      TRACE(PAK_ADDRESS & 0xff);
		      TRACE(PAK_ADDRESS >> 8);

		      set_bus_outputs();
		      set_data_bus(pak_memory[PAK_ADDRESS]);
		    }
		}
	      
	    }
	}

      //----------------------------------------------------------------------


      //----------------------------------------------------------------------
      // SMR handling
      
      if( (last_smr == 0) && (smr == 1) )
	{
	  ss_address = 0;
	}

#endif
      // If soe goes high then we have to make bus inputs
      // If ss is low as well then it's a write
      if( (last_soe == 0) && (soe == 1) )
	{
	  int data;
	  
	  // High so don't drive the data bus, this is a write
	  // Capture data on bus
	  set_bus_inputs();

	  // If ss is low, then this is a write as OE is attached to WR on RAMPAKs
	  // CE is gated with SMR so that can stop the write
	  if( (ss == 0) && (spgm == 0) )
	    {
	      data = get_data_bus();

	      if( smr == 1 )
		{
		}
	      else
		{
#if !READ_ONLY	      
		  // write to ram
		  //pak_memory[PAK_ADDRESS] = data;
#endif
		}
	    }
	}

      // catch-all, force inputs
      if( soe )
	{
	  set_bus_inputs();
	}
      
      last_ss     = ss;
      last_sclk   = sclk;
      last_soe    = soe;
      last_smr    = smr;
      last_spgm   = spgm;
      
    }

#endif
}

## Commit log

2021-08-13 Initial check in of PCB files
    [pak_breakout-B_Cu.gbr, pak_breakout-B_Mask.gbr, pak_breakout-B_Paste.gbr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]
2021-08-13 Re-arranged directoruies, added fab1 errata for picopak
    [pak_breakout.kicad_pcb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]
2021-08-16 Second PCB with errata fixed added
    [picopak-B_Cu.gbr, picopak-B_Mask.gbr, picopak-B_Paste.gbr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]
2021-09-01 Added RUN jumper for drag-drop upgrade, SWD pads moved
    [picopak.kicad_pcb, picopak.sch, picopak_orig.sch]
2021-09-16 Updated errata and updated code
    [pak-gadget.c]
2021-09-24 V1_2 PCB laid out
    [picopak-B_Cu.gbr, picopak-B_Mask.gbr, picopak-B_Paste.gbr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]
2021-11-13 Updates. Archive file for PCB
    [picopak.kicad_pcb, picopak.sch]
2021-11-19 Trace of failed boot added
